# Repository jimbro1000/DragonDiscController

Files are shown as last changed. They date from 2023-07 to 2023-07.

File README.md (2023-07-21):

# Dragon 32/64 Disk Controller Card #

This project contains the design and build
documents for a recreation of the DragonDos
disc controller
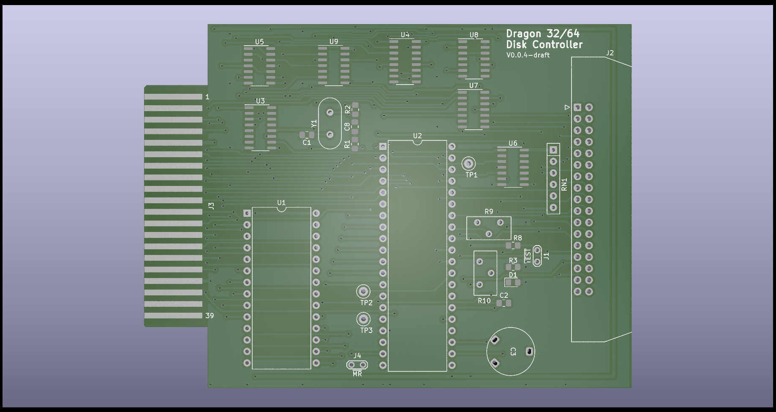
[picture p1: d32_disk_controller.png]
render of controller pdb


## Design ##

The schematics use a WDC WD2797 disc controller
IC as the core of the board, this is consistent
with the original DragonData design. Other 
2797 ICs from different manufacturers should
still work

Other than the rom and controller the discrete
logic chips are surface mount to help with the
availability of components. In all cases the
surface mount parts are of the largest versions
available to try and make the assembly of the
board feasible for hand soldering

## Progress ##

In the current state the board is untested

The PCB layout is (very) generous on dimensions
and needs work to shrink it down. Iterating on
this won't change the functionality and should
significantly reduce the size of the board, and
hence the cost of fabrication

## Assembly and BoM ##

Until the board progresses to a point where it
can be tested the assembly instructions and the
proven bill of materials are left unpublished

## Calibration ##

1. Adjust the RPW timing - measure the pulse
width of the TG43 signal from pin 29 on U2. 
Use R10 to fix the pulse at 600ns

2. Adjust the WPW timing - measure the pulse
width of the signal from pin 3 of U6, pin 31 of U2,
or pin 22 of the IDC connector (the IDC pin is
inverted). Use R9 to fix the pulse at 300ns

3. Adjust VC0 timing - measure the frequency
of the DIRC signal from pin 1 of U6, pin 16 of U2,
or pin 18 of the IDC connector (the IDC pin is
inverted). Use C3 to set the signal at 250KHz

### Complete Adjustment Procedure ###

The official documentation identifies a more
complex and thorough adjustment procedure.
Where !TEST is referenced you can use the test
point on the board at J1. Pin 1 is connected to
!TEST on U2 (pin 22)

#### Write Precompensation ####

1. Set !TEST to high (1)
2. Strobe !MR on U2 Pin 19
3. Set !TEST to low (0)
4. Measure pulse width on U2 Pin 31
5. Adjust R9 until pulse width is 300ns
6. Set !TEST to high (1)

#### Data Separator ####

1. Set !Test to high (1)
2. Strobe !MR on U2 pin 19
3. Check that !5/8 and !DDEN are set properly. U2 pin 17 and 37
4. Set !TEST to low (0)
5. Measure pulse width on U2 Pin 29
6. Adjust R10 until pulse width is 600ns
7. Measure frequency on U2 pin 16
8. Adjust C3 until frequency is 250KHz
9. Set !TEST to high (1)

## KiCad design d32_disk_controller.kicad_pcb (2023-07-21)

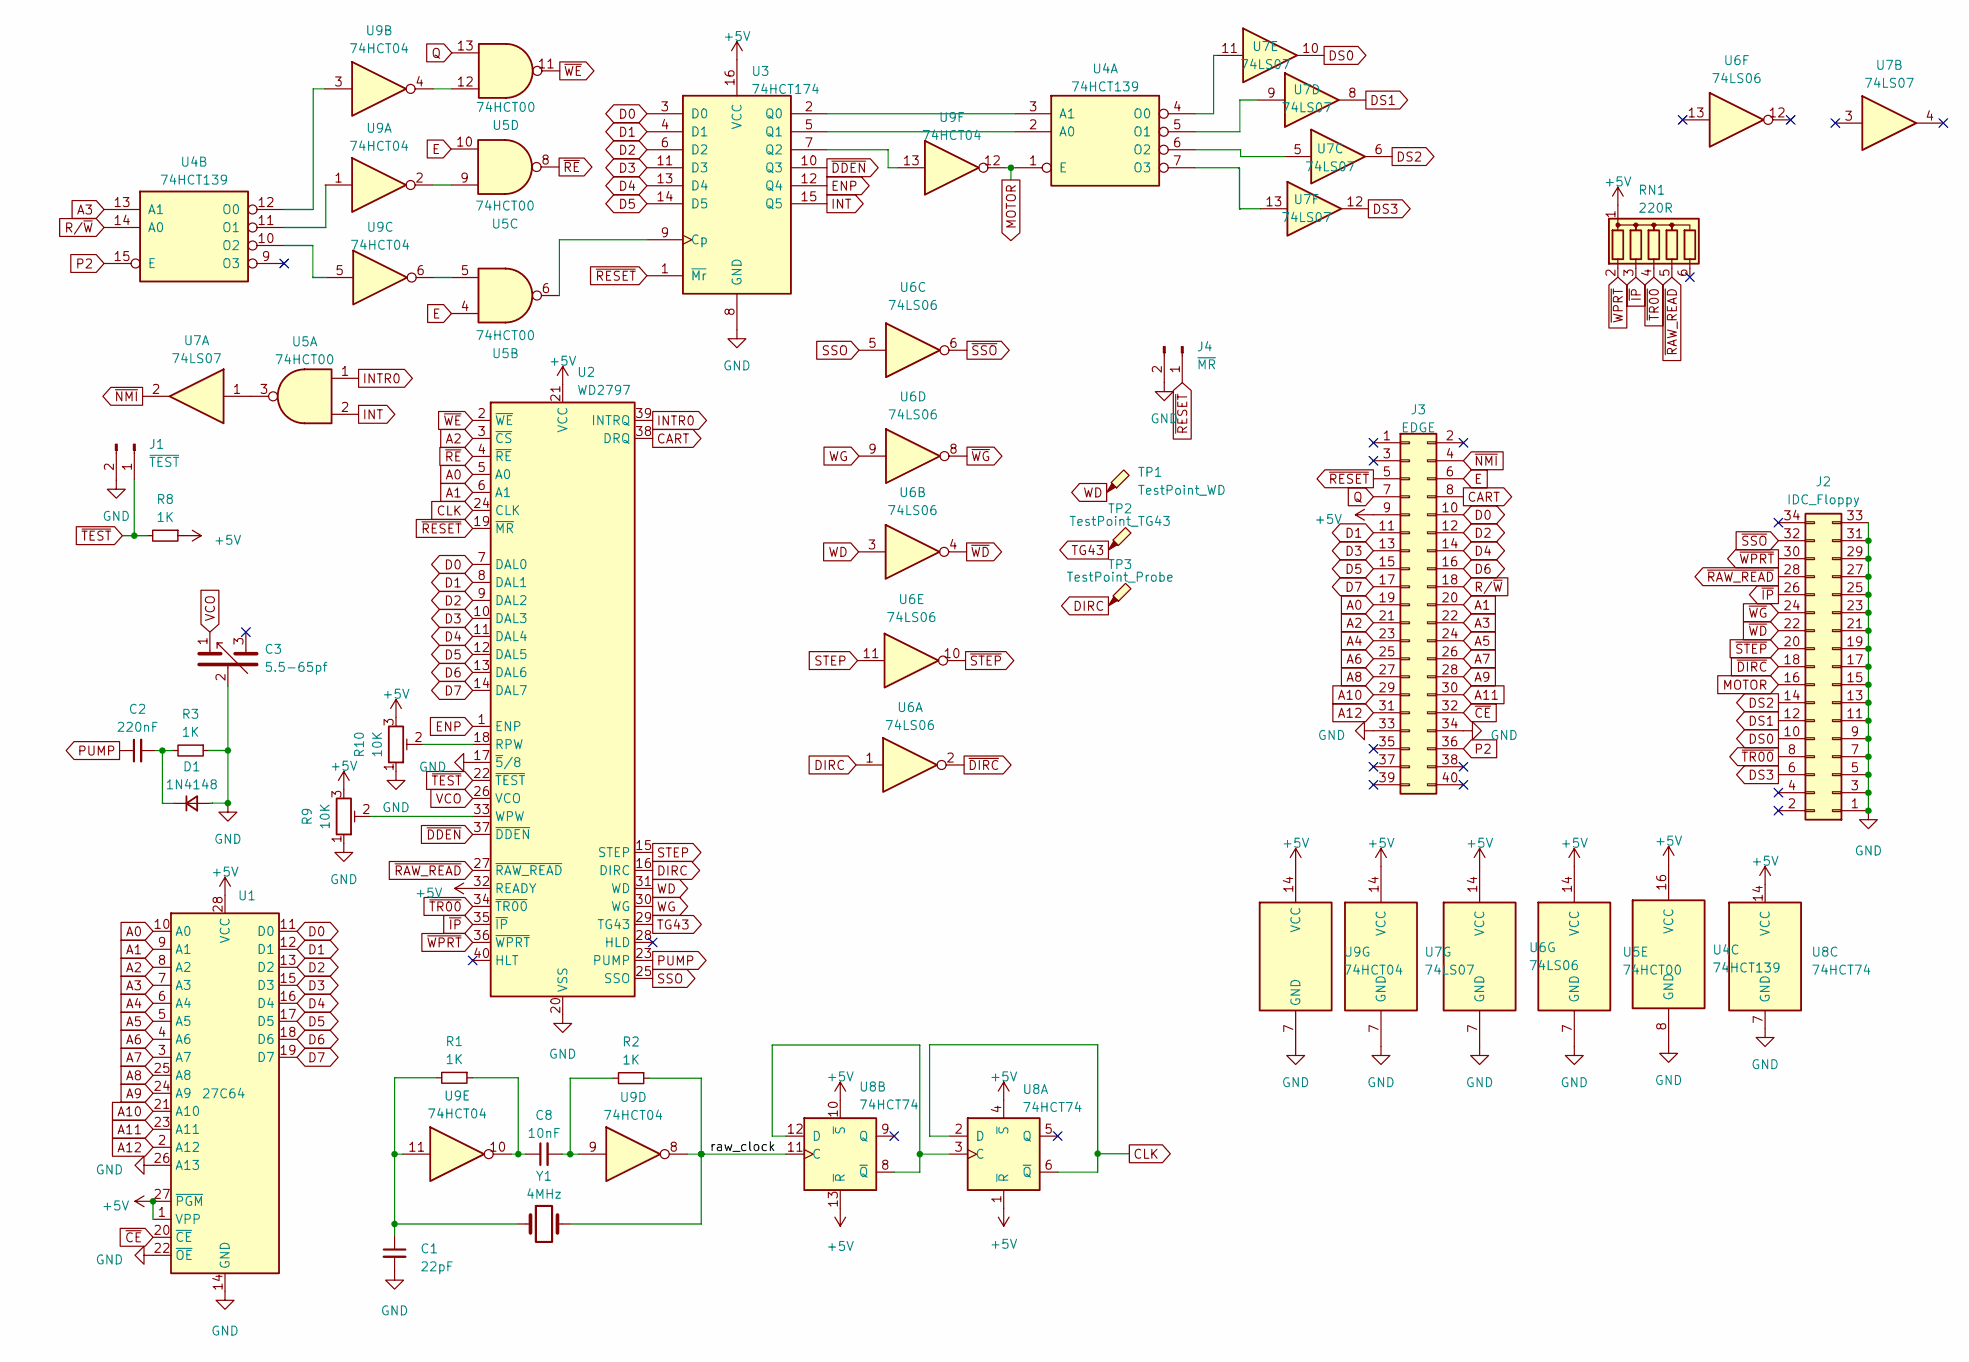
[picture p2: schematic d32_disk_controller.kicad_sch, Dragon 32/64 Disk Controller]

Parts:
C1: 22pF; C_0805_2012Metric_Pad1.18x1.45mm_HandSolder
C2: 220nF; C_0805_2012Metric_Pad1.18x1.45mm_HandSolder
C3: 5.5-65pf; Trimmer-10mm
C8: 10nF; C_0805_2012Metric_Pad1.18x1.45mm_HandSolder
D1: 1N4148; D_0805_2012Metric_Pad1.15x1.40mm_HandSolder
J1: ~{TEST}; TestPoint_2Pads_Pitch2.54mm_Drill0.8mm
J2: IDC_Floppy; IDC-Header_2x17_P2.54mm_Latch_Horizontal
J3: EDGE; D32_Edge
J4: ~{MR}; TestPoint_2Pads_Pitch2.54mm_Drill0.8mm
R1, R2, R3, R8: 1K; R_0805_2012Metric_Pad1.20x1.40mm_HandSolder
R9, R10: 10K; Potentiometer_Bourns_3296Y_Vertical
RN1: 220R; R_Array_SIP6
TP1: TestPoint_WD; TestPoint_Loop_D2.50mm_Drill1.0mm
TP2: TestPoint_TG43; TestPoint_Loop_D2.50mm_Drill1.0mm
TP3: TestPoint_Probe; TestPoint_Loop_D2.50mm_Drill1.0mm
U1: 27C64; DIP-28_W15.24mm
U2: WD2797; DIP-40_W15.24mm
U3: 74HCT174; SOIC-16_3.9x9.9mm_P1.27mm; DigiKey 296-9260-5-ND
U4: 74HCT139; SOIC-16_3.9x9.9mm_P1.27mm; DigiKey 296-SN74HCT139DBRCT-ND
U5: 74HCT00; SOIC-14_3.9x8.7mm_P1.27mm; DigiKey 296-14860-1-ND
U6: 74LS06; SOIC-14_3.9x8.7mm_P1.27mm
U7: 74LS07; SOIC-14_3.9x8.7mm_P1.27mm; DigiKey 296-14877-1-ND
U8: 74HCT74; SOIC-14_3.9x8.7mm_P1.27mm; DigiKey 296-1211-1-ND
U9: 74HCT04; SOIC-14_3.9x8.7mm_P1.27mm; DigiKey 296-1205-1-ND
Y1: 4MHz; Crystal_HC18-U_Vertical

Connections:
+5V: J3.9, R8.1, R9.3, R10.3, RN1.1 (common), U1.1 (VPP), U1.27 (~PGM), U1.28 (VCC), U2.21 (VCC), U2.32 (READY), U3.16 (VCC), U4.16 (VCC), U5.14 (VCC), U6.14 (VCC), U7.14 (VCC), U8.1 (~R), U8.4 (~S), U8.10 (~S), U8.13 (~R), U8.14 (VCC), U9.14 (VCC)
/raw_clock: R2.1, U8.11 (C), U9.8, Y1.2
A0: J3.19, U1.10 (A0), U2.5 (A0)
A1: J3.20, U1.9 (A1), U2.6 (A1)
A2: J3.21, U1.8 (A2), U2.3 (~CS)
A3: J3.22, U1.7 (A3), U4.13 (A1)
A4: J3.23, U1.6 (A4)
A5: J3.24, U1.5 (A5)
A6: J3.25, U1.4 (A6)
A7: J3.26, U1.3 (A7)
A8: J3.27, U1.25 (A8)
A9: J3.28, U1.24 (A9)
A10: J3.29, U1.21 (A10)
A11: J3.30, U1.23 (A11)
A12: J3.31, U1.2 (A12)
CART: J3.8, U2.38 (DRQ)
CLK: U2.24 (CLK), U8.2 (D), U8.6 (~Q)
D0: J3.10, U1.11 (D0), U2.7 (DAL0), U3.3 (D0)
D1: J3.11, U1.12 (D1), U2.8 (DAL1), U3.4 (D1)
D2: J3.12, U1.13 (D2), U2.9 (DAL2), U3.6 (D2)
D3: J3.13, U1.15 (D3), U2.10 (DAL3), U3.11 (D3)
D4: J3.14, U1.16 (D4), U2.11 (DAL4), U3.13 (D4)
D5: J3.15, U1.17 (D5), U2.12 (DAL5), U3.14 (D5)
D6: J3.16, U1.18 (D6), U2.13 (DAL6)
D7: J3.17, U1.19 (D7), U2.14 (DAL7)
DIRC: TP3.1, U2.16 (DIRC), U6.1
DS0: J2.10, U7.10
DS1: J2.12, U7.8
DS2: J2.14, U7.6
DS3: J2.6, U7.12
E: J3.6, U5.4, U5.10
ENP: U2.1 (ENP), U3.12 (Q4)
GND: C1.2, C3.2, D1.2 (A), J1.2, J2.1, J2.3, J2.5, J2.7, J2.9, J2.11, J2.13, J2.15, J2.17, J2.19, J2.21, J2.23, J2.25, J2.27, J2.29, J2.31, J2.33, J3.33, J3.34, J4.2, R3.1, R9.1, R10.1, U1.14 (GND), U1.22 (~OE), U1.26 (A13), U2.17 (~5/8), U2.20 (VSS), U3.8 (GND), U4.8 (GND), U5.7 (GND), U6.7 (GND), U7.7 (GND), U8.7 (GND), U9.7 (GND)
INT: U3.15 (Q5), U5.2
INTR0: U2.39 (INTRQ), U5.1
MOTOR: J2.16, U4.1 (E), U9.12
unnamed: C1.1, R1.2, U9.11, Y1.1
unnamed: C8.1, R1.1, U9.10
unnamed: C8.2, R2.2, U9.9
unnamed: C2.2, D1.1 (K), R3.2
unnamed: R10.2, U2.18 (RPW)
unnamed: R9.2, U2.33 (WPW)
unnamed: U3.9 (Cp), U5.6
unnamed: U3.2 (Q0), U4.3 (A1)
unnamed: U3.5 (Q1), U4.2 (A0)
unnamed: U3.7 (Q2), U9.13
unnamed: U4.4 (O0), U7.11
unnamed: U4.5 (O1), U7.9
unnamed: U4.6 (O2), U7.5
unnamed: U4.7 (O3), U7.13
unnamed: U4.12 (O0), U9.3
unnamed: U4.11 (O1), U9.1
unnamed: U4.10 (O2), U9.5
unnamed: U5.3, U7.1
unnamed: U5.5, U9.6
unnamed: U5.9, U9.2
unnamed: U5.12, U9.4
unnamed: U8.3 (C), U8.8 (~Q), U8.12 (D)
P2: J3.36, U4.15 (E)
PUMP: C2.1, U2.23 (PUMP)
Q: J3.7, U5.13
R/~W: J3.18, U4.14 (A0)
SSO: U2.25 (SSO), U6.5
STEP: U2.15 (STEP), U6.11
TG43: TP2.1, U2.29 (TG43)
VCO: C3.1, U2.26 (VCO)
WD: TP1.1, U2.31 (WD), U6.3
WG: U2.30 (WG), U6.9
~CE: J3.32, U1.20 (~CE)
~DDEN: U2.37 (~DDEN), U3.10 (Q3)
~DIRC: J2.18, U6.2
~IP: J2.26, RN1.3 (R2), U2.35 (~IP)
~NMI: J3.4, U7.2
~RAW_READ: J2.28, RN1.5 (R4), U2.27 (~RAW_READ)
~RESET: J3.5, J4.1, U2.19 (~MR), U3.1 (~Mr)
~RE: U2.4 (~RE), U5.8
~SSO: J2.32, U6.6
~STEP: J2.20, U6.10
~TEST: J1.1, R8.2, U2.22 (~TEST)
~TR00: J2.8, RN1.4 (R3), U2.34 (~TR00)
~WD: J2.22, U6.4
~WE: U2.2 (~WE), U5.11
~WG: J2.24, U6.8
~WPRT: J2.30, RN1.2 (R1), U2.36 (~WPRT)

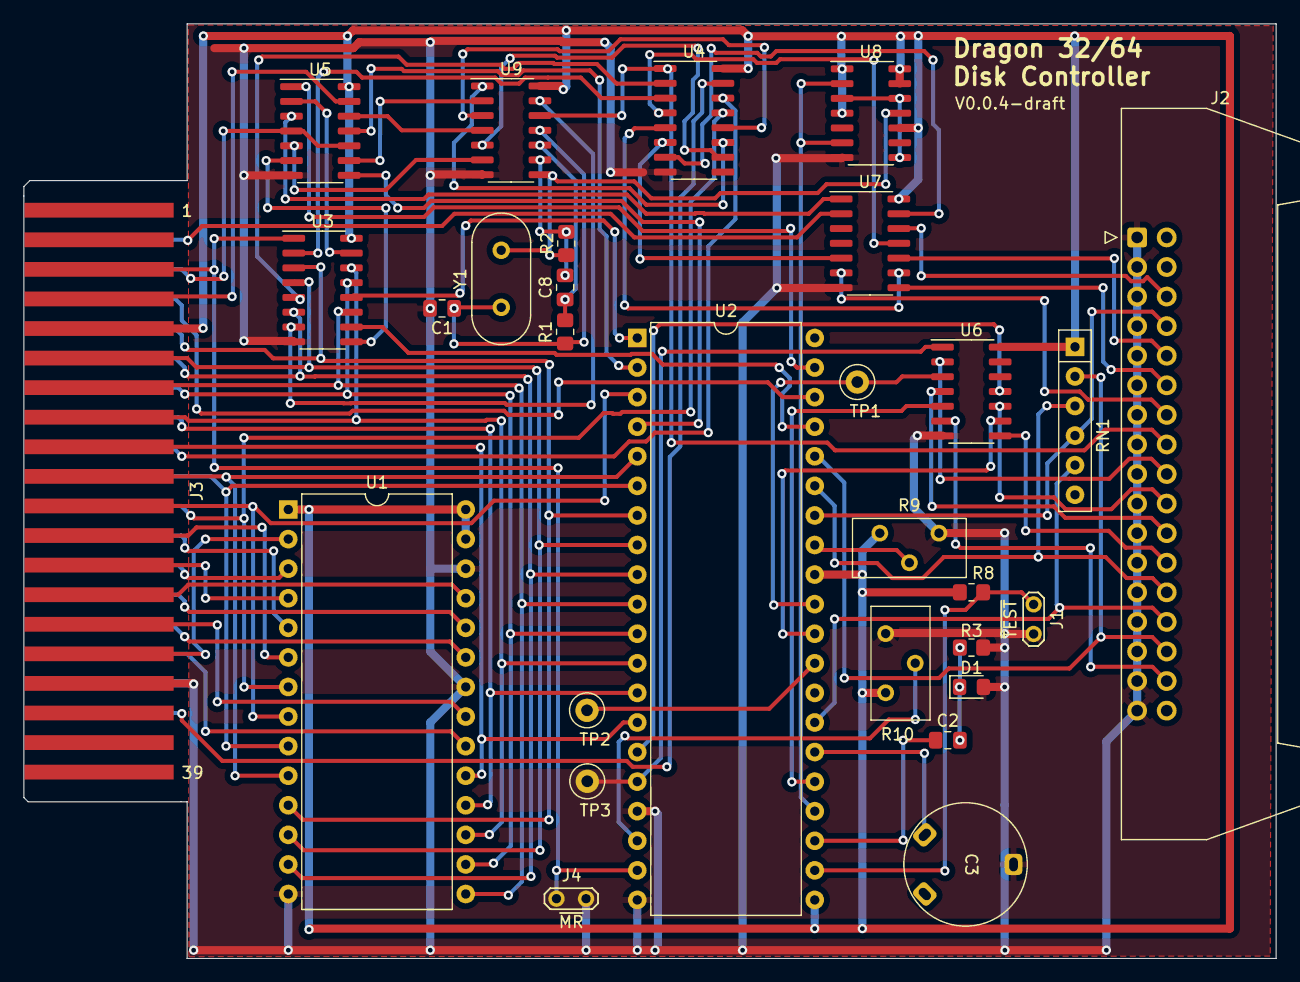
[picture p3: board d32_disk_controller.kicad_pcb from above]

Board: 2 copper layers, 107.5 x 80.3 mm, 29 parts (0 on the bottom side), 84 nets.

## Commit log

2023-07-05 redraft traces
    [d32_disk_controller.kicad_pcb]
2023-07-05 rework traces
    [d32_disk_controller.kicad_pcb]
2023-07-06 revise tracing
    [d32_disk_controller.kicad_pcb]
2023-07-06 verify component availability
    [d32_disk_controller.kicad_pcb, d32_disk_controller.kicad_sch]
2023-07-06 update version
    [d32_disk_controller.kicad_pcb, d32_disk_controller.kicad_sch]
2023-07-21 revise board for better component selection
    [d32_disk_controller.kicad_pcb, d32_disk_controller.kicad_sch]
2023-07-21 update from component selection change
    [d32_disk_controller.kicad_pcb, d32_disk_controller.kicad_sch]
2023-07-21 add test points
    [d32_disk_controller.kicad_pcb, d32_disk_controller.kicad_sch]
